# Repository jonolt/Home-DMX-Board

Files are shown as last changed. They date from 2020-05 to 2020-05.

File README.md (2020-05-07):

# Home DMX - Hardware

is a simple arduino based DMX controller to controll led lights installed in your home to be used with DMX controllers and relais.

**Please Contact me if you wonna use the board, there may be unducumented bugs.**

The Firmware can be found in a extra git repository: [Home-DMX-Firmaware](https://github.com/jonolt/Home-DMX-Firmaware).

This Project started with [Home-DMX-Control](https://github.com/jonolt/Home-DMX-Control). Firmware and hardware are now in two repositories.

## Idea

The selection for the lighting scene in daily use should be as simple as possible. Therefore exactly two push buttons are used to move up and down in a list of lighting scenes. Since I am not a fan of idle transformers, a conventional light switch is used in my application to switch the whole system on and off. In the same way a corresponding scene could be set.

The individual scenes should be adjustable directly on the controller without additional hardware. The input of the scenes works like on lighting control desks without motor faders via potentiometer and buttons. To make the firmware easy (without programmer and co) and maintainable by everyone, an Arduino was used, because it has a USB converter and the IDE is easy to use and install.

The board has a DMX output and 4 PWM/IO Outputs as well as 2 inputs for button.

## Structure

The MAX481 (U2) is a transceiver for RS-485 and RS-422 communication based on DMX. It uses the TX and RX pins of the arduino. For a visual control of the DMX communication Leds are connected via buffer (U61).

Digital inputs and outputs a isolated via optocouplers (additional circuits are required to switch larger loads).

The display is controlled serially (SPI) via the library provided by the manufacturer.

The switches can be hardware or software or both debaunced. Theres also the option to connect them via diodes (D1-D4) to a interupt pin.

The board does not has to be fully equipt with the componets.

**External Power must be disconnected when programming the Ardino, when a DC/DC converter is used!**

### Hardware Logic (Isolated)

#### Button Input

A total of 4 buttons can be placed on the pcb. While SW2 and SW3 are hard wired SW1 and SW4 can be set up in 4 different ways to safe pins to use the hardware interupt:

1. **1 buttons 0 extra IO**: SW1 or SW2 are connected only to the Interrupt pin via Diode D1/D4 or a bridge at D1/D4. If an innterupt is triggered, and neither SW2 or SW3 pin is pulled low, SW1 or SW4 must have been pressed.
2. **2 buttons 1 extra IO**: as in one but with JP1/JP2 bridged and SW1/SW4 fully equiped.
3. **2 buttons 2 extra IO**: equip all parts and bridge JP1 and JP2. Interrupt can still be used for other things.
4. **1 buttons 1 extra IO**: as in 3. but with either SW1 or SW4

Of course the swictehs can be used withiout the interrupt by ommiting the diodes. In fact even the low pass filete can be ommited with proper software debouncing.

All Switches and the interupt line are pulled up by R1 to R4 and R9. R4, C1 ect. build low pass filter for hardware debouncing and can be ommited (with the resistors bridged).

Swicth 2 and 3 have an additional Isolated input for external switches operating on another voltage level or with different ground.

#### LCD-Display

The LCD-Display is controlled by 3 Wire SPI connected to the Hardwre SPI of the microcontroller. The MISO master input is not required for the display and is kept free in case additional SPI devices are added (for example via a shield). The Backlight is PWM dimmed (D11) via the transisor Q1.

#### Expansion Connector J1 J2

The Connector(s) has the identical pinout as the Arduino Micro. Also you could use a stackable female connector strip directly with the Arduino.

#### LEDs

In addition to a power LED (D6), there are various Status LEDs on the front side (pcb-back) showing the correct function of the PWM Outputs (D20-23) and the DMX Interface (D60, D61). The LED of the Arduino can be used as a system LED if D13 is not used otherwise.

### Hardware Interfaces (Unisoltated)

All outputs and inputs (connectors) are isolated by default to each other. Resitor Bridges bridges can be apllied (1XX, 2XX) to break those isolations, see chapter Hardware Bridging.

#### X30 - Button Input

Simple current limiting Resistor R30 and R31 for diode of the photocoupler. Needs to be selected for each application by the input voltage V_IN with the formular:

R=(V_IN-V_F)/I_F, V_F=1.2V I_F=20mA

#### X40 - PWM/Output

These autputs can be used in 2 ways. As digital output with pullups and as Low Side switch (max 50mA, V_CE=0.1-0.2V).

The voltage for the pullups can cpme from the connector, directly bridged from the input power (R140) or via the linear voltage regulator U140, R142 and R143 (kater ones bridging isolation).

The emmiters of the photocouplers can be accessed directly via J41-J43 and J40-2. Conection between those can be broken at the Jumpers JP40-JP42. This way all four outputs can be used iolsated to each other.

#### X50 - Power In

Power input conssits of two parts revers voltage protection and DCDC-Converter. The reverse voltage protection is a siple p channel circuit. For the DCDC-Converter are two footprints obove each other. One for a SIL7 package (with pins 1,2,4,6 connected) and one for a SIL8 package (with pin (1, 2, (3), 6, 7 connected) to allow for different converters to be installed.

#### X60 - DMX

DMX uses the TX/RX pins of the arduino. The MAX481 (U60) is a common RS-485 tranciver. See [www.mathertel.de/Arduino/DMXShield.aspx](http://www.mathertel.de/Arduino/DMXShield.aspx) for a detailed description.

### Hardware Bridging

Danger Zone. Only assemble these components if you know what you are doing as this will bridge isolations.

#### 1XX

Bridges between unisolated interfaces:

- **R130, R131**: VIN/GND to PWM/Ouitput
- **R140, R141**: VIN/GND to Button Input

#### 2XX

Bridges between unisolated interfaces and isolated internal circuit:

- **J250, J251**: Connect these Pads with a wire to use the buildin voltage regulator of the arduino (VIN).
- **R260-R264**: Bypass isolation of DMX interface.

## License and Copyright

Copyright (C) 2019, 2020 Johannes Nolte
 
This program is free software: you can redistribute it and/or modify
it under the terms of the GNU General Public License as published by
the Free Software Foundation, version 2.1 only.

This program is distributed in the hope that it will be useful,
but WITHOUT ANY WARRANTY; without even the implied warranty of
MERCHANTABILITY or FITNESS FOR A PARTICULAR PURPOSE.  See the
GNU General Public License for more details.

You should have received a copy of the GNU General Public License
along with this program.  If not, see <https://www.gnu.org/licenses/>.

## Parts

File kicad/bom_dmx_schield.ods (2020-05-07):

 |  |  |  |  |  | Source: | /home/johannes/LRZPrivat/Sebastian/Home-DMX-Control/board/dmx_schield.sch
 |  |  |  |  |  | Date: | Sat 02 May 2020 13:36:19 CEST
 |  |  |  |  |  | Tool: | Eeschema 5.0.2+dfsg1-1
 |  |  |  |  |  | Generator: | /usr/share/kicad/plugins/bom_csv_grouped_by_value_with_fp.py
 |  |  |  |  |  | Component Count: | 102
 |  | All | Seb Qt | Sum All | Sum Seb | Ref | Qnty | Value | Cmp name | Footprint | Description | Vendor
KEM X5R0805 1,0U | 8 | 0.07 € | 4 | 0.28 € | 0.28 € | C3, C2, C1, C4, | 4 | 1u | C | Capacitor_SMD:C_0805_2012Metric | Unpolarized capacitor
KEM X7R0805 100N | 2 | 0.05 € | 0 | 0.10 € | 0.00 € | C6, C60, | 2 | 0,1uF | C | Capacitor_SMD:C_0805_2012Metric | Unpolarized capacitor
KEM X7R1206 4,7N | 2 | 0.02 € | 1 | 0.02 € | 0.02 € | C50, | 1 | 4,7uF/50V | C | Capacitor_SMD:C_1206_3216Metric | Unpolarized capacitor
KEM X7R1206 2,2N | 2 | 0.06 € | 1 | 0.06 € | 0.06 € | C51, | 1 | 2,2uF/50V | C | Capacitor_SMD:C_1206_3216Metric | Unpolarized capacitor
KEM X5R0805 10U | 1 | 0.15 € | 0 | 0.15 € | 0.00 € | C61, | 1 | 10uF | C | Capacitor_SMD:C_1206_3216Metric | Unpolarized capacitor
BAS 85 SMD | 6 | 0.05 € | 2 | 0.20 € | 0.10 € | D3, D2, D4, D1, | 4 | BAS85 | D_Schottky | Diode_SMD:D_MicroMELF | Schottky diode
OSO LHR974 | 2 | 0.05 € | 1 | 0.05 € | 0.05 € | D6, | 1 | LH R974 | LED | LED_SMD:LED_0805_2012Metric | Light emitting diode
TZMC15 | 2 | 0.30 € | 1 | 0.30 € | 0.30 € | D50, | 1 | TZM15 | D_Zener | Diode_SMD:D_SC-80 | Zener diode
OSO LGR971 | 10 | 0.05 € | 4 | 0.30 € | 0.20 € | D61, D60, D23, D22, D21, D20, | 6 | LG R971 | LED | LED_SMD:LED_0805_2012Metric | Light emitting diode
- | 8 | 0.00 € | 4 | 0.00 € | 0.00 € | H1, H2, H3, H4, | 4 | MountingHole | MountingHole | MountingHole:MountingHole_3.2mm_M3_DIN965 | Mounting Hole without connection
MPE 094-1-007 + MPE 094-1-010 | 2 | 0.49 € | 0 | 0.98 € | 0.00 € | J1, J2, | 2 | Conn_01x17 | Conn_01x17 | Connector_PinSocket_2.54mm:PinSocket_1x17_P2.54mm_Vertical | Generic connector, single row, 01x17, script generated (kicad-library-utils/schlib/autogen/connector/)
AKL 382-04 + AKL 369-04 | 2 | 1.52 € | 1 | 1.52 € | 1.52 € | J30, | 1 | Conn_01x04 | Conn_01x04 | Connector_Phoenix_MC:PhoenixContact_MC_1,5_4-G-3.81_1x04_P3.81mm_Horizontal | Generic connector, single row, 01x04, script generated (kicad-library-utils/schlib/autogen/connector/)
AKL 382-06 + AKL 369-06 | 2 | 2.00 € | 1 | 2.00 € | 2.00 € | J40, | 1 | Conn_01x06 | Conn_01x06 | Connector_Phoenix_MC:PhoenixContact_MC_1,5_6-G-3.81_1x06_P3.81mm_Horizontal | Generic connector, single row, 01x06, script generated (kicad-library-utils/schlib/autogen/connector/)
AKL 382-02 + AKL 369-02 | 2 | 0.75 € | 1 | 0.75 € | 0.75 € | J50, | 1 | Conn_01x02 | Conn_01x02 | Connector_Phoenix_MC:PhoenixContact_MC_1,5_2-G-3.81_1x02_P3.81mm_Horizontal | Generic connector, single row, 01x02, script generated (kicad-library-utils/schlib/autogen/connector/)
AKL 382-03 + AKL 369-03 | 1 | 1.14 € | 0 | 1.14 € | 0.00 € | J60, | 1 | Conn_01x03 | Conn_01x03 | Connector_Phoenix_MC:PhoenixContact_MC_1,5_3-G-3.81_1x03_P3.81mm_Horizontal | Generic connector, single row, 01x03, script generated (kicad-library-utils/schlib/autogen/connector/)
- | 5 |  |  | 0.00 € | 0.00 € | J251, J250, J42, J41, J43, | 5 | Conn_01x01 | Conn_01x01 | Connector_Wire:SolderWirePad_1x01_Drill0.8mm | Generic connector, single row, 01x01, script generated (kicad-library-utils/schlib/autogen/connector/)
- | 2 |  |  | 0.00 € | 0.00 € | JP1, JP2, | 2 | SolderJumper_2_Open | SolderJumper_2_Open | Jumper:SolderJumper-2_P1.3mm_Open_Pad1.0x1.5mm | Solder Jumper, 2-pole, open
- | 3 |  |  | 0.00 € | 0.00 € | JP40, JP41, JP42, | 3 | SolderJumper_2_Bridged | SolderJumper_2_Bridged | Jumper:SolderJumper-2_P1.3mm_Bridged_Pad1.0x1.5mm | Solder Jumper, 2-pole, closed/bridged
BOU SRN4018-4R7M | 2 | 0.25 € | 1 | 0.25 € | 0.25 € | L50, | 1 | 4,7uH/1.15A | L | Inductor_SMD:L_Bourns-SRN4018 | Inductor
EA DOGM162E-A (evtl L/S) + EA LED55X31-A (W) | 2 | 11.95 € | 1 | 11.95 € | 11.95 € | LCD1, | 1 | EADOGM162 | EADOGM162 | my_LCD:EA DOGM 162
BSR 14 SMD | 2 | 0.07 € | 1 | 0.07 € | 0.07 € | Q1, | 1 | BSR14 | Q_NPN_BEC | Package_TO_SOT_SMD:SOT-23 | NPN transistor, base/emitter/collector
IRLML 5203 | 2 | 0.25 € | 1 | 0.25 € | 0.25 € | Q50, | 1 | IRLML5203 | Q_PMOS_GSD | Package_TO_SOT_SMD:SOT-23 | P-MOSFET transistor, gate/source/drain
RND 0805 1 10K | 9 | 0.00 € |  | 0.00 € | 0.00 € | R1, R3, R2, R40, R41, R42, R43, R4, R9, | 9 | 10k | R | Resistor_SMD:R_0805_2012Metric | Resistor
optional | 2 | 0.00 € | 0 | 0.00 € | 0.00 € | R10, R11, | 2 | 5-10k | R | Resistor_SMD:R_0805_2012Metric | Resistor
RND 0805 1 10 | 1 |  |  | 0.00 € | 0.00 € | R12, | 1 | 10 | R | Resistor_SMD:R_0805_2012Metric | Resistor
RND 0805 1 1K | 5 | 0.00 € |  | 0.00 € | 0.00 € | R13, R7, R6, R5, R8, | 5 | 1,0k | R | Resistor_SMD:R_0805_2012Metric | Resistor
RND 0805 1 330 | 1 | 0.00 € |  | 0.00 € | 0.00 € | R14, | 1 | 330 | R | Resistor_SMD:R_0805_2012Metric | Resistor
RND 0805 1 560 | 2 |  |  | 0.00 € | 0.00 € | R31, R30, | 2 | 540@12V | R | Resistor_SMD:R_0805_2012Metric | Resistor
RND 0805 1 100K | 1 | 0.00 € |  | 0.00 € | 0.00 € | R50, | 1 | 100k | R | Resistor_SMD:R_0805_2012Metric | Resistor
RND 0805 1 120 | 1 | 0.00 € |  | 0.00 € | 0.00 € | R60, | 1 | 120 | R | Resistor_SMD:R_0805_2012Metric | Resistor
RND 0805 1 560 | 2 |  |  | 0.00 € | 0.00 € | R62, R61, | 2 | 562 | R | Resistor_SMD:R_0805_2012Metric | Resistor
RND 0805 1 300 | 6 |  |  | 0.00 € | 0.00 € | R64, R20, R21, R22, R23, R63, | 6 | 300 | R | Resistor_SMD:R_0805_2012Metric | Resistor
RND 0805 1 0 | 9 |  |  | 0.00 € | 0.00 € | R130, R261, R260, R262, R263, R264, R131, R140, R141, | 9 | 0 | R | Resistor_SMD:R_0805_2012Metric | Resistor
RND 0805 1 240 | 1 |  |  | 0.00 € | 0.00 € | R142, | 1 | 240 | R | Resistor_SMD:R_0805_2012Metric | Resistor
find si sho was | 1 | 0.00 € | 0 | 0.00 € | 0.00 € | R143, | 1 | e.g. 2k | R | Resistor_SMD:R_0805_2012Metric | Resistor
ACP 9-LRS 10K + ACHSE ACP 9 G | 4 | 0.32 € | 2 | 0.64 € | 0.64 € | RV1, RV2, | 2 | 10k | R_POT | Potentiometer_THT:Potentiometer_ACP_CA9-V10_Vertical | Potentiometer
OMR B3FS-1012P | 7 | 0.32 € | 3 | 1.28 € | 0.96 € | SW1, SW3, SW2, SW4, | 4 | SW_Push | SW_Push | Button_Switch_SMD:SW_SPST_PTS645 | Push button switch, generic, two pins
1S7E_1205S1.5UP | 2 | 3.10 € | 1 | 3.10 € | 3.10 € | U1, | 1 | TEC 2-2411WI | DCDC-SIP8-1-2-(3)-6-7 | my_lib:SIP8-1-2-3-5-6-7-8 | DCDC Converter Single SIL Package
LTV 847S | 2 | 0.65 € | 1 | 0.65 € | 0.65 € | U3, | 1 | LTV-847S | LTV-847S | Package_DIP:SMDIP-16_W7.62mm | DC Optocoupler, Vce 35V, CTR 50%, SMDIP-16
LTV 827S | 1 | 0.25 € | 0 | 0.25 € | 0.00 € | U5, | 1 | LTV-827S | LTV-827S | Package_DIP:SMDIP-8_W7.62mm | DC Optocoupler, Vce 35V, CTR 50%, SMDIP-8
ADUM 1301 ARW | 1 | 2.30 € | 0 | 2.30 € | 0.00 € | U6, | 1 | ADUM1301 | ADUM1301 | Package_SO:SOIC-16W_7.5x10.3mm_P1.27mm | Triple-Channel Digital Isolators
REE-0505S | 1 | 2.90 € | 0 | 2.90 € | 0.00 € | U7, | 1 | REE-0505S/1S7E_0505S1.5UP | DCDC-SIP7-1-2-4-6 | my_lib:SIP7-1-2-4-6 | DCDC Converter Single SIL Package
2S7WA_0505S3RP | 1 | 8.25 € | 0 | 8.25 € | 0.00 € | U11, | 1 | DCDC-SIP7-1-2-4-6 | DCDC-SIP7-1-2-4-6 | my_lib:SIP7-1-2-4-6 | DCDC Converter Single SIL Package
MAX 481 CSA | 1 | 3.10 € | 0 | 3.10 € | 0.00 € | U60, | 1 | MAX481E | MAX481E | Package_SO:PowerIntegrations_SO-8 | Half duplex RS-485/RS-422, 2.5 Mbps, Â±15kV electro-static discharge (ESD) protection, no slew-rate, with low-power shutdown, with receiver/driver enable, 32 receiver drive kapacitity, DIP-8 and SOIC-8
74LVC2G34 | 1 | 0.00 € |  | 0.00 € | 0.00 € | U61, | 1 | 74LVC2G34 | 74LVC2G34 | Package_TO_SOT_SMD:SOT-23-6 | Dual Buffer, Low-Voltage CMOS, power-pins
LM 317 MDCYR | 1 | 0.78 € |  | 0.78 € | 0.00 € | U140, | 1 | LM317_3PinPackage | LM317_3PinPackage | Package_TO_SOT_SMD:SOT-223-3_TabPin2 | 1A 35V Adjustable Linear Regulator, SOT-89/SOT-223/TO-220/TO-252/TO-263
ARDUINO MICRO WOH | 2 | 17.30 € | 1 | 17.30 € | 17.30 € | XA1, | 1 | Arduino_Micro_Socket | Arduino_Micro_Socket | Arduino:Arduino_Micro_Socket | Socket for Arduino Micro
Board | 1 | 10.30 € | 1 | 10.30 € | 10.30 €
 |  |  |  | 71.22 € | 50.75 €
 |  |  |  |  |  | U1x1, U11x1
3S7A_0505S1.5UP |  | 6.40 €
TMH 0505S |  | 6.65

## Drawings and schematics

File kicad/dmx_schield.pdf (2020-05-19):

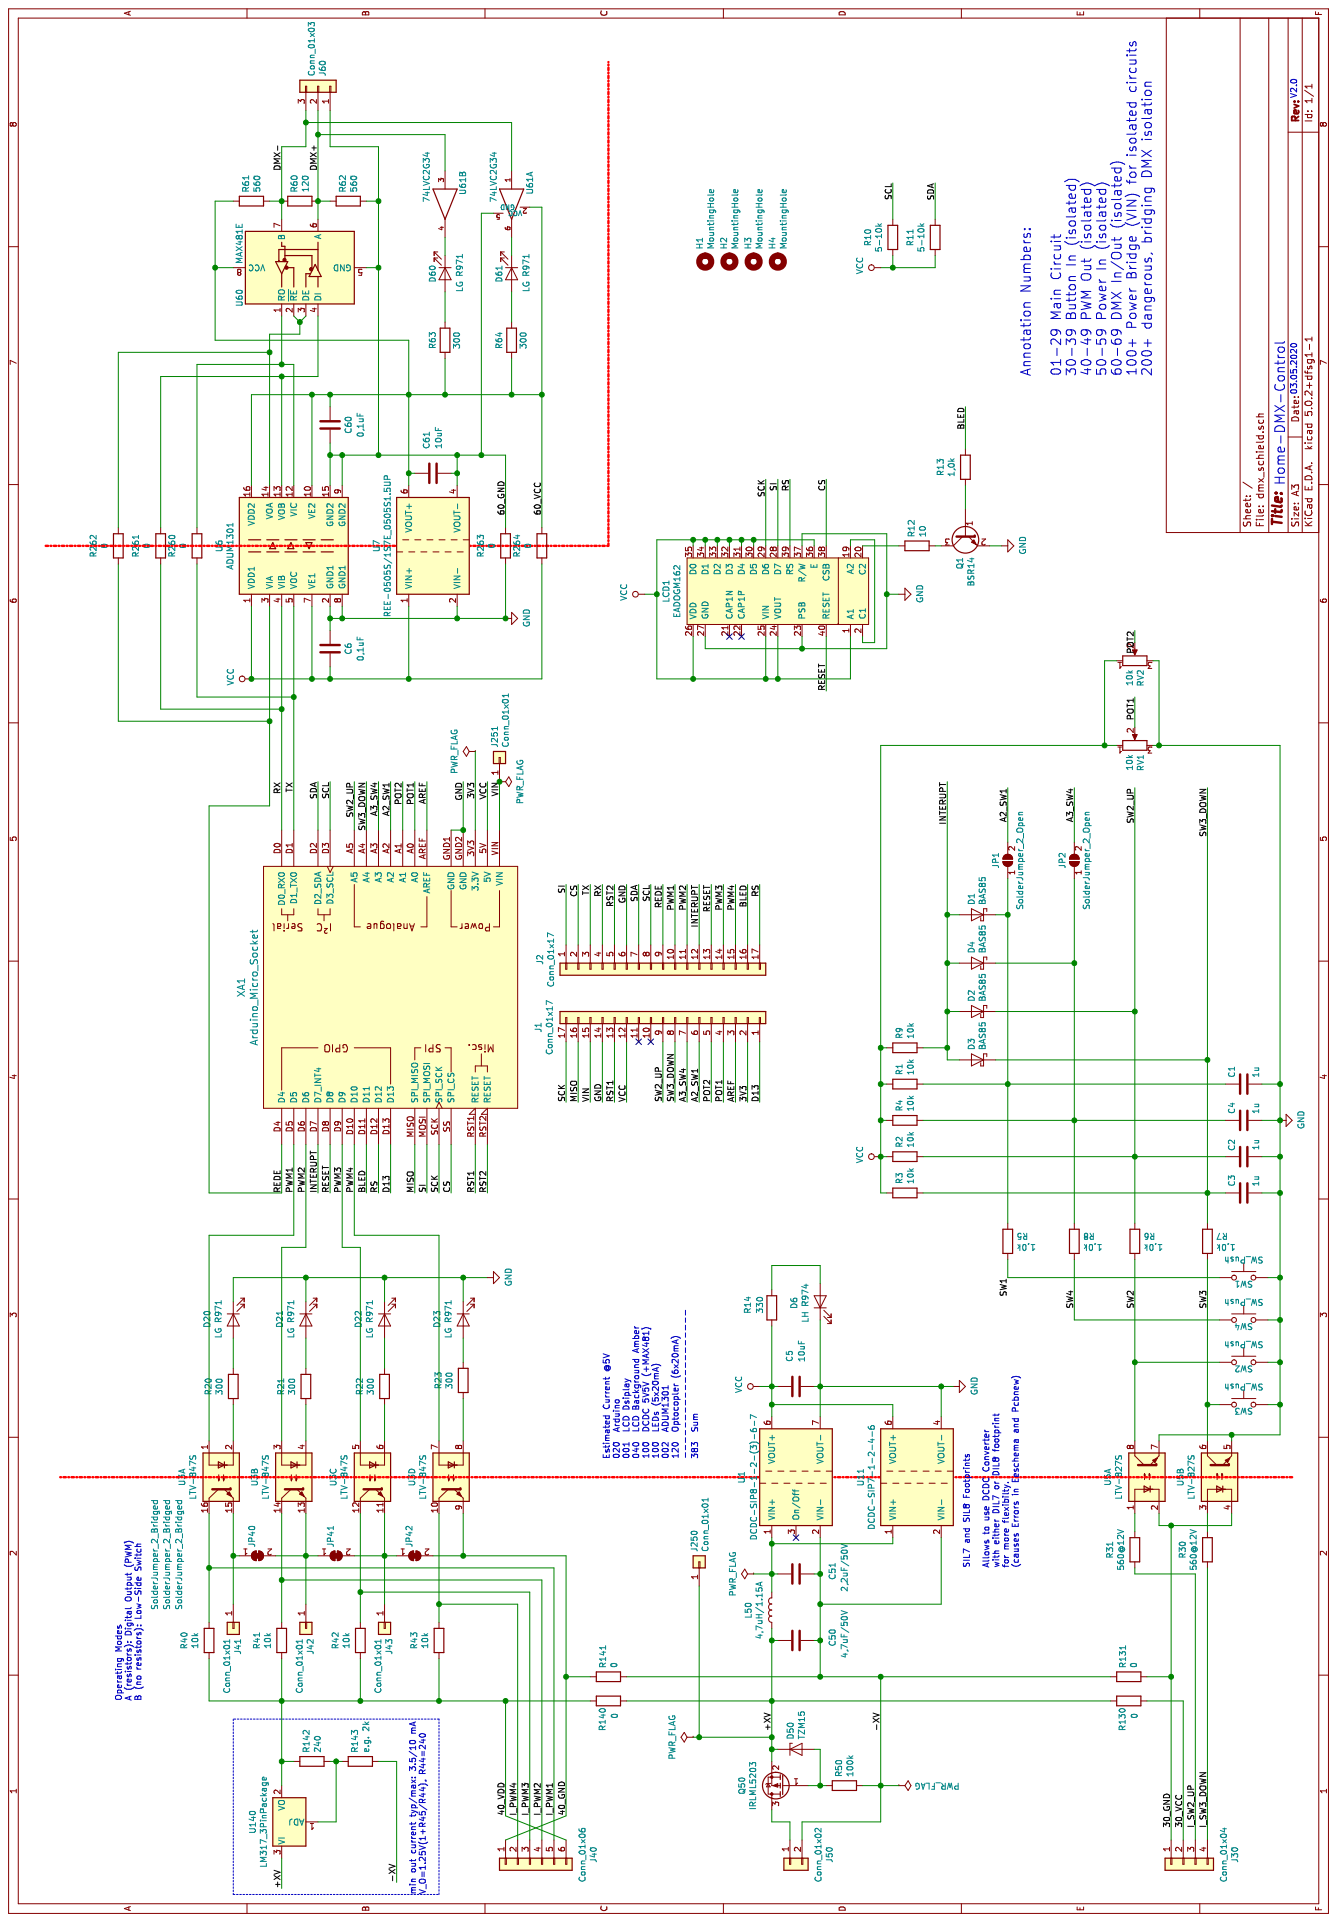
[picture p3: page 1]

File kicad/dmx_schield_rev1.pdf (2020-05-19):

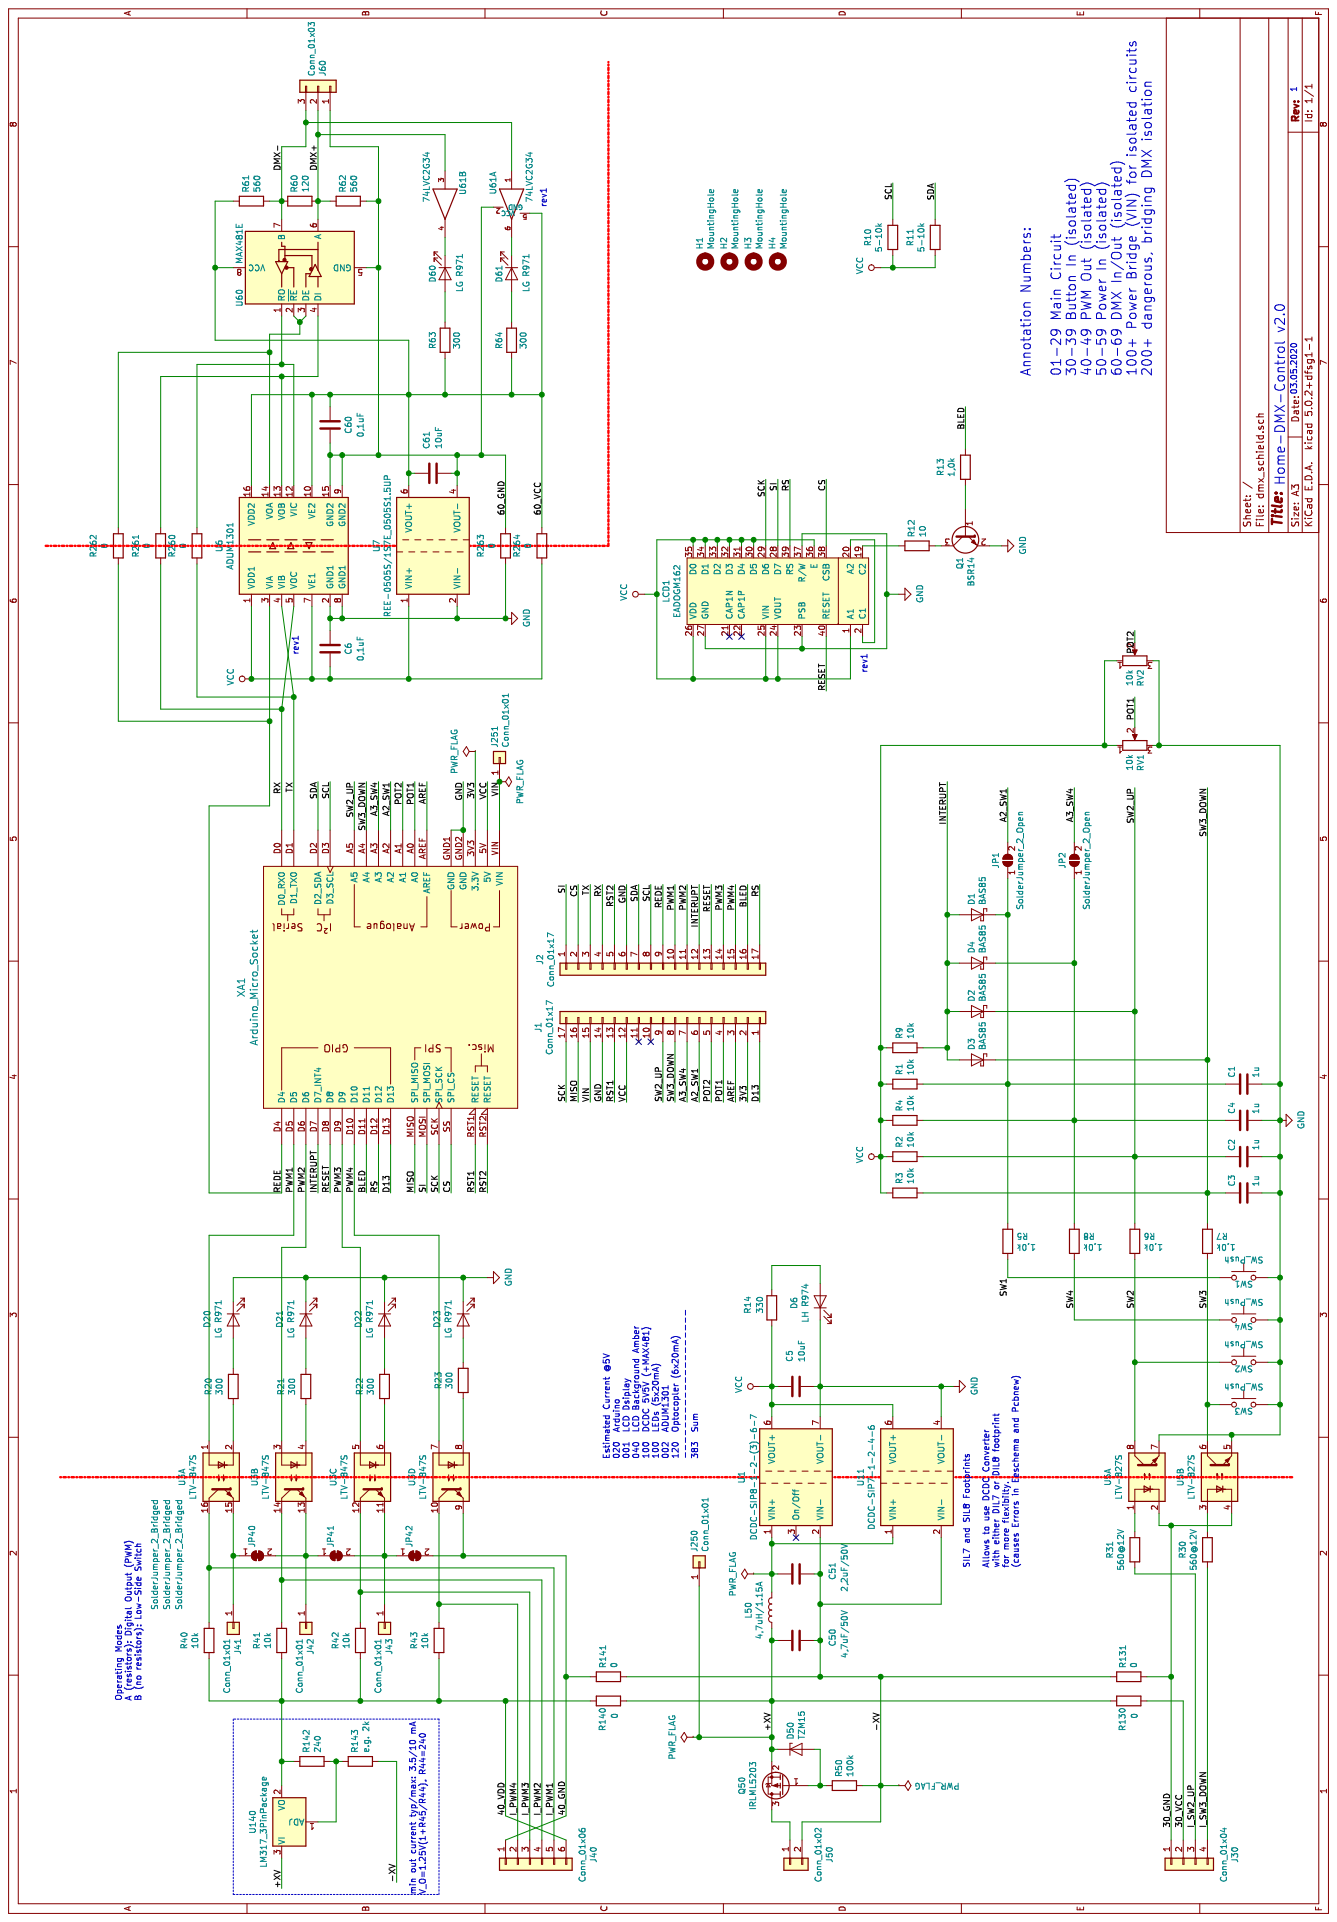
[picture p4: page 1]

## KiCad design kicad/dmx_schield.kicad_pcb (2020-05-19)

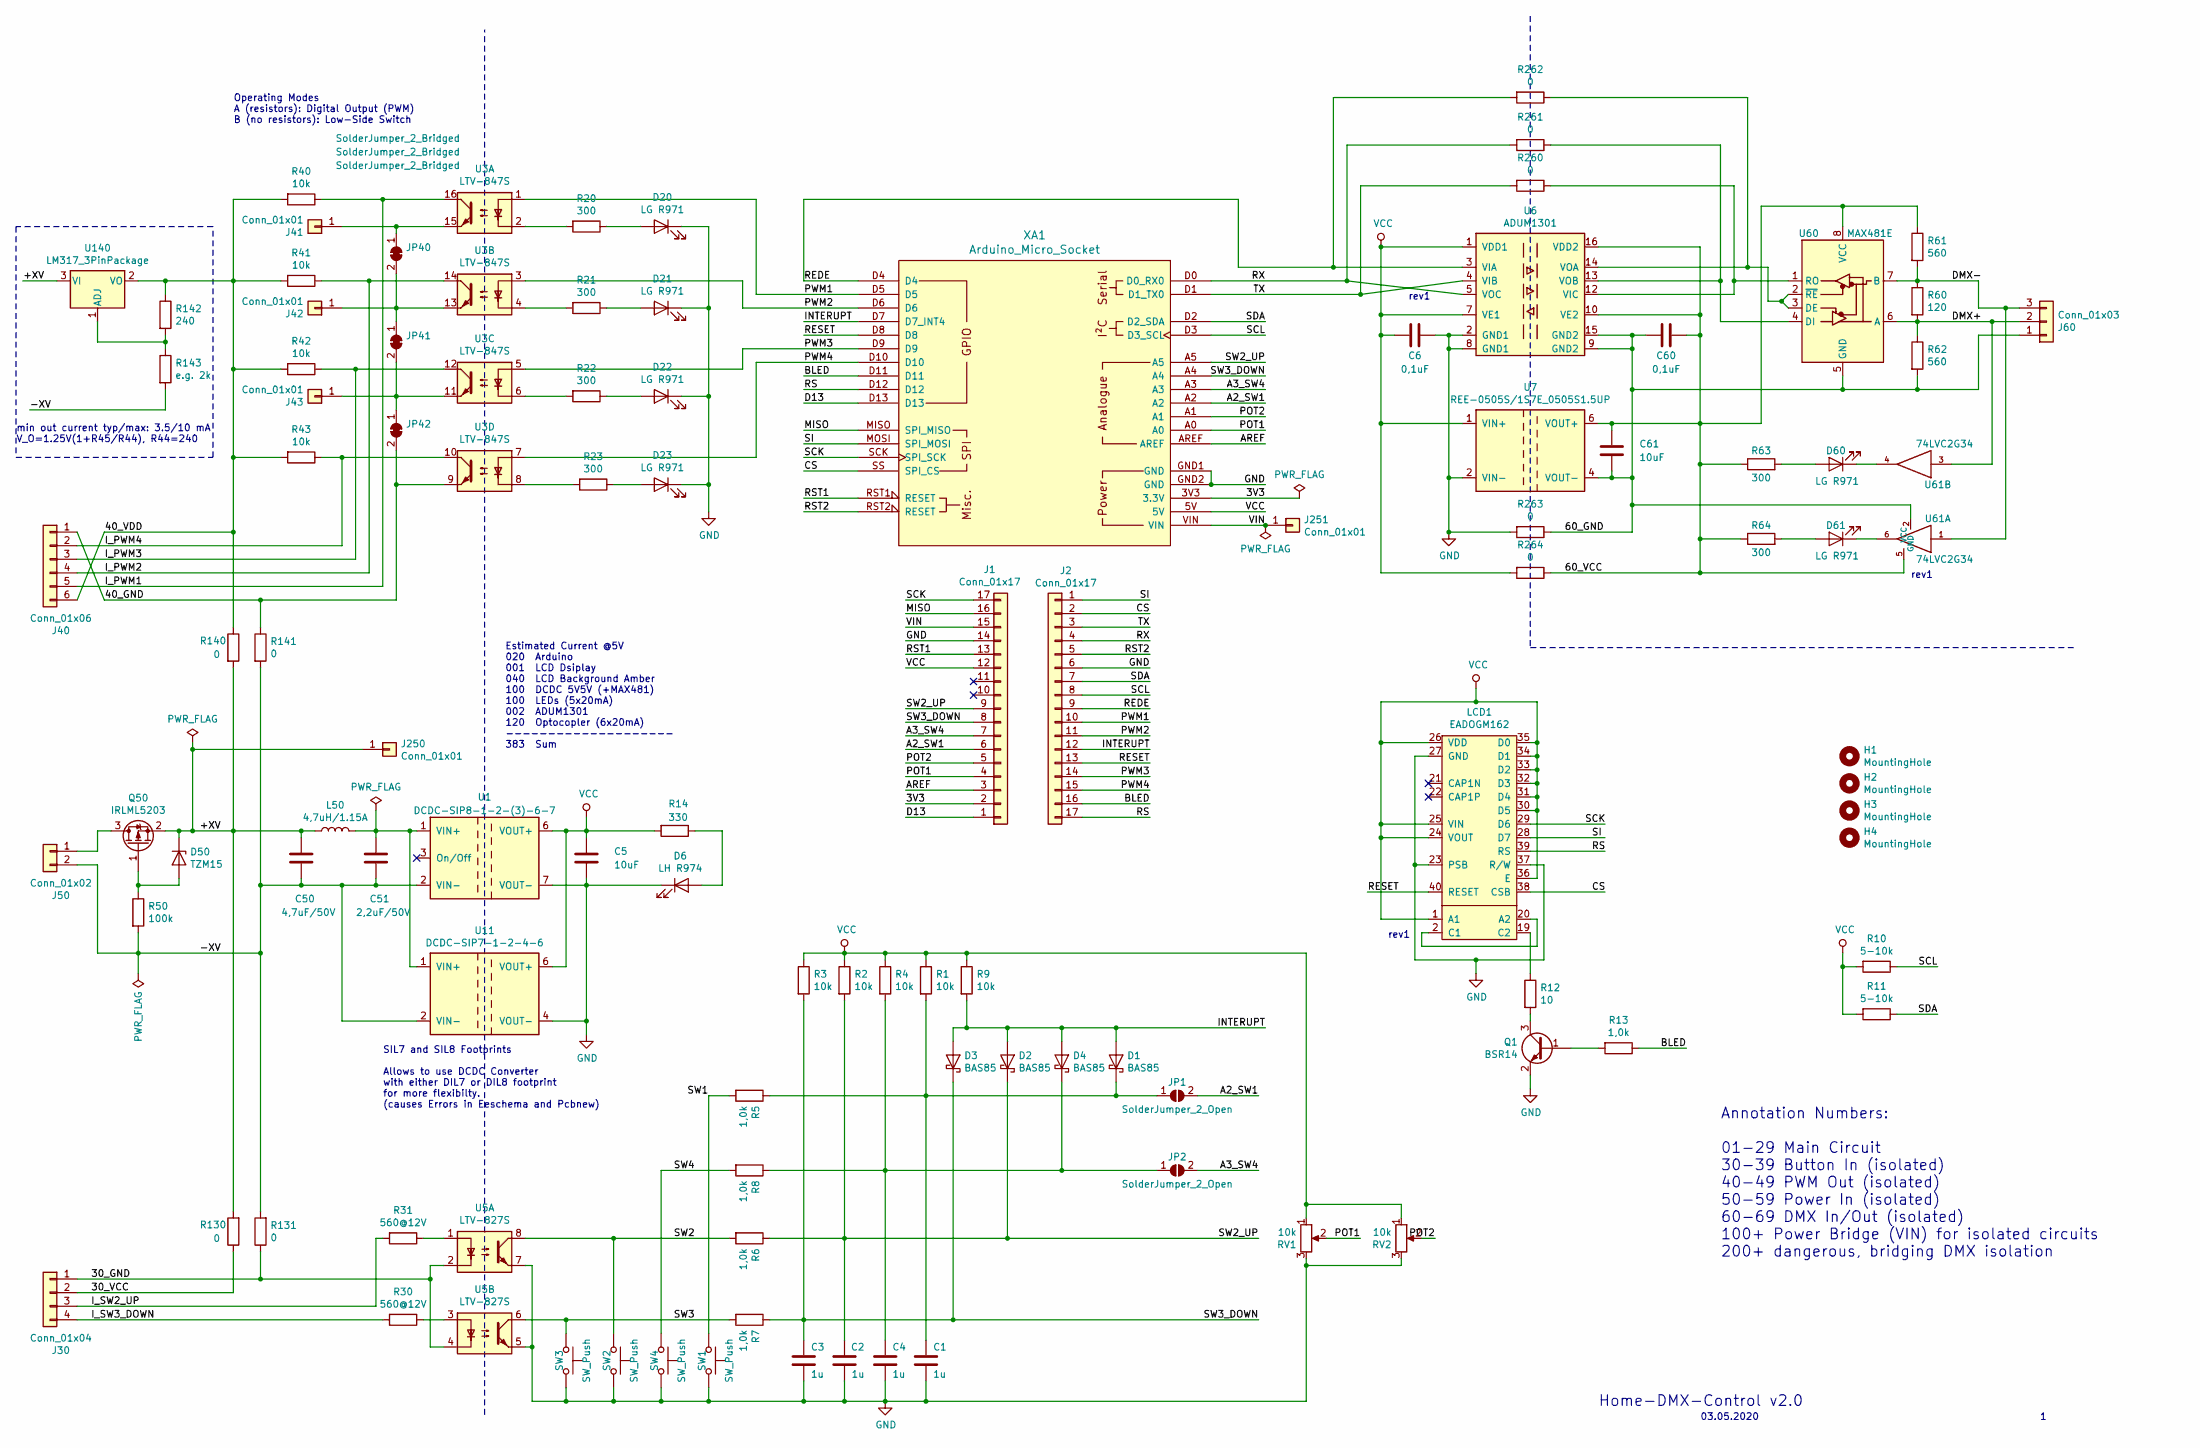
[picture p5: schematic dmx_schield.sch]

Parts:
C1, C2, C3, C4: 1u; C_0805_2012Metric
C5, C61: 10uF; C_1206_3216Metric
C6, C60: 0,1uF; C_0805_2012Metric
C50: 4,7uF/50V; C_1206_3216Metric
C51: 2,2uF/50V; C_1206_3216Metric
D1, D2, D3, D4: BAS85; D_MicroMELF
D6: LH R974; LED_0805_2012Metric
D20, D21, D22, D23, D60, D61: LG R971; LED_0805_2012Metric
D50: TZM15; D_SC-80
H1, H2, H3, H4: MountingHole; MountingHole_3.2mm_M3_DIN965
J1, J2: Conn_01x17; PinSocket_1x17_P2.54mm_Vertical
J30: Conn_01x04; PhoenixContact_MC_1,5_4-G-3.81_1x04_P3.81mm_Horizontal
J40: Conn_01x06; PhoenixContact_MC_1,5_6-G-3.81_1x06_P3.81mm_Horizontal
J41, J42, J43, J250, J251: Conn_01x01; SolderWirePad_1x01_Drill0.8mm
J50: Conn_01x02; PhoenixContact_MC_1,5_2-G-3.81_1x02_P3.81mm_Horizontal
J60: Conn_01x03; PhoenixContact_MC_1,5_3-G-3.81_1x03_P3.81mm_Horizontal
JP1, JP2: SolderJumper_2_Open; SolderJumper-2_P1.3mm_Open_Pad1.0x1.5mm
JP40, JP41, JP42: SolderJumper_2_Bridged; SolderJumper-2_P1.3mm_Bridged_Pad1.0x1.5mm
L50: 4,7uH/1.15A; L_Bourns-SRN4018
LCD1: EADOGM162; EA_DOGM_162
Q1: BSR14; SOT-23
Q50: IRLML5203; SOT-23
R1, R2, R3, R4, R9, R40, R41, R42, R43: 10k; R_0805_2012Metric
R5, R6, R7, R8, R13: 1,0k; R_0805_2012Metric
R10, R11: 5-10k; R_0805_2012Metric
R12: 10; R_0805_2012Metric
R14: 330; R_0805_2012Metric
R20, R21, R22, R23, R63, R64: 300; R_0805_2012Metric
R30, R31: 560@12V; R_0805_2012Metric
R50: 100k; R_0805_2012Metric
R60: 120; R_0805_2012Metric
R61, R62: 560; R_0805_2012Metric
R130, R131, R140, R141, R260, R261, R262, R263, R264: 0; R_0805_2012Metric
R142: 240; R_0805_2012Metric
R143: e.g. 2k; R_0805_2012Metric
RV1, RV2: 10k; Potentiometer_ACP_CA9-V10_Vertical
SW1, SW2, SW3, SW4: SW_Push; SW_SPST_PTS645
U1: DCDC-SIP8-1-2-(3)-6-7; SIP8-1-2-3-5-6-7-8
U3: LTV-847S; SMDIP-16_W7.62mm
U5: LTV-827S; SMDIP-8_W7.62mm
U6: ADUM1301; SOIC-16W_7.5x10.3mm_P1.27mm
U7: REE-0505S/1S7E_0505S1.5UP; SIP7-1-2-4-6
U11: DCDC-SIP7-1-2-4-6; SIP7-1-2-4-6
U60: MAX481E; PowerIntegrations_SO-8
U61: 74LVC2G34; SOT-23-6
U140: LM317_3PinPackage; SOT-223-3_TabPin2
XA1: Arduino_Micro_Socket

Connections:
/3V3: J1.2, XA1.3V3 (3.3V)
/30_GND: J30.1, R131.1, U5.2, U5.4
/30_VCC: J30.2, R130.1
/40_GND: J40.1, JP42.2 (B), R141.1, U3.9
/40_VDD: J40.6, R40.2, R41.2, R42.2, R43.2, R140.1, R142.1, U140.2 (VO)
/60_GND: C60.2, C61.1, J60.1, R62.2, R263.1, U6.9 (GND2), U6.15 (GND2), U7.4 (VOUT-), U60.5 (GND), U61.2 (GND)
/60_VCC: C60.1, C61.2, R61.1, R63.1, R64.1, R264.1, U6.10 (VE2), U6.16 (VDD2), U7.6 (VOUT+), U60.8 (VCC), U61.5 (VCC)
/+XV: C50.1, D50.1 (K), J250.1, L50.1, Q50.2 (S), R130.2, R140.2, U140.3 (VI)
/-XV: C50.2, C51.2, J50.2, R50.2, R131.2, R141.2, R143.2, U1.2 (VIN-), U11.2 (VIN-)
/A2_SW1: J1.6, JP1.2 (B), XA1.A2
/A3_SW4: J1.7, JP2.2 (B), XA1.A3
/AREF: J1.3, XA1.AREF
/BLED: J2.16, R13.1, XA1.D11
/CS: J2.2, LCD1.38 (CSB), XA1.SS (SPI_CS)
/D13: J1.1, XA1.D13
/DMX+: J60.2, R60.2, R62.1, U60.6 (A), U61.3
/DMX-: J60.3, R60.1, R61.2, U60.7 (B), U61.1
/INTERUPT: D1.2 (A), D2.2 (A), D3.2 (A), D4.2 (A), J2.12, R9.2, XA1.D7 (D7_INT4)
/I_PWM1: J40.5, R40.1, U3.16
/I_PWM2: J40.4, R41.1, U3.14
/I_PWM3: J40.3, R42.1, U3.12
/I_PWM4: J40.2, R43.1, U3.10
/I_SW2_UP: J30.3, R31.2
/I_SW3_DOWN: J30.4, R30.2
/MISO: J1.16, XA1.MISO (SPI_MISO)
/POT1: J1.4, RV1.2, XA1.A0
/POT2: J1.5, RV2.2, XA1.A1
/PWM1: J2.10, U3.1, XA1.D5
/PWM2: J2.11, U3.3, XA1.D6
/PWM3: J2.14, U3.5, XA1.D9
/PWM4: J2.15, U3.7, XA1.D10
/REDE: J2.9, R262.2, U6.3 (VIA), XA1.D4
/RESET: J2.13, LCD1.40 (RESET), XA1.D8
/RS: J2.17, LCD1.39 (RS), XA1.D12
/RST1: J1.13, XA1.RST1 (RESET)
/RST2: J2.5, XA1.RST2 (RESET)
/RX: J2.4, R261.2, U6.5 (VOC), XA1.D0 (D0_RX0)
/SCK: J1.17, LCD1.29 (D6), XA1.SCK (SPI_SCK)
/SCL: J2.8, R10.1, XA1.D3 (D3_SCL)
/SDA: J2.7, R11.1, XA1.D2 (D2_SDA)
/SI: J2.1, LCD1.28 (D7), XA1.MOSI (SPI_MOSI)
/SW1: R5.2, SW1.1
/SW2: R6.2, SW2.1, U5.8
/SW2_UP: C2.1, D2.1 (K), J1.9, R2.2, R6.1, XA1.A5
/SW3: R7.2, SW3.1, U5.6
/SW3_DOWN: C3.1, D3.1 (K), J1.8, R3.2, R7.1, XA1.A4
/SW4: R8.2, SW4.1
/TX: J2.3, R260.2, U6.4 (VIB), XA1.D1 (D1_TX0)
/VIN: J1.15, J251.1, XA1.VIN
GND: C1.2, C2.2, C3.2, C4.2, C5.1, C6.1, D6.1 (K), D20.1 (K), D21.1 (K), D22.1 (K), D23.1 (K), J1.14, J2.6, LCD1.23 (PSB), LCD1.27 (GND), LCD1.37 (R/W), Q1.2 (E), R263.2, RV1.3, RV2.3, SW1.2, SW2.2, SW3.2, SW4.2, U1.7 (VOUT-), U5.5, U5.7, U6.2 (GND1), U6.8 (GND1), U7.2 (VIN-), U11.4 (VOUT-), XA1.GND1 (GND), XA1.GND2 (GND)
unnamed: C1.1, D1.1 (K), JP1.1 (A), R1.2, R5.1
unnamed: C4.1, D4.1 (K), JP2.1 (A), R4.2, R8.1
unnamed: C51.1, L50.2, U1.1 (VIN+), U11.1 (VIN+)
unnamed: D6.2 (A), R14.1
unnamed: D20.2 (A), R20.1
unnamed: D21.2 (A), R21.1
unnamed: D22.2 (A), R22.1
unnamed: D23.2 (A), R23.1
unnamed: D50.2 (A), Q50.1 (G), R50.1
unnamed: D60.1 (K), U61.4
unnamed: D60.2 (A), R63.2
unnamed: D61.1 (K), U61.6
unnamed: D61.2 (A), R64.2
unnamed: J41.1, JP40.1 (A), U3.15
unnamed: J42.1, JP40.2 (B), JP41.1 (A), U3.13
unnamed: J43.1, JP41.2 (B), JP42.1 (A), U3.11
unnamed: J50.1, Q50.3 (D)
unnamed: LCD1.2 (C1), LCD1.20 (A2)
unnamed: LCD1.19 (C2), R12.1
unnamed: Q1.1 (B), R13.2
unnamed: Q1.3 (C), R12.2
unnamed: R20.2, U3.2
unnamed: R21.2, U3.4
unnamed: R22.2, U3.6
unnamed: R23.2, U3.8
unnamed: R30.1, U5.3
unnamed: R31.1, U5.1
unnamed: R142.2, R143.1, U140.1 (ADJ)
unnamed: R260.1, U6.12 (VIC), U60.1 (RO)
unnamed: R261.1, U6.13 (VOB), U60.4 (DI)
unnamed: R262.1, U6.14 (VOA), U60.2 (~RE), U60.3 (DE)
VCC: C5.2, C6.2, J1.12, LCD1.1 (A1), LCD1.24 (VOUT), LCD1.25 (VIN), LCD1.26 (VDD), LCD1.30 (D5), LCD1.31 (D4), LCD1.32 (D3), LCD1.33 (D2), LCD1.34 (D1), LCD1.35 (D0), LCD1.36 (E), R1.1, R2.1, R3.1, R4.1, R9.1, R10.2, R11.2, R14.2, R264.2, RV1.1, RV2.1, U1.6 (VOUT+), U6.1 (VDD1), U6.7 (VE1), U7.1 (VIN+), U11.6 (VOUT+), XA1.5V

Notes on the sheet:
03.05.2020
Operating Modes A (resistors): Digital Output (PWM) B (no resistors): Low-Side Switch
Estimated Current @5V 020 Arduino 001 LCD Dsiplay 040 LCD Background Amber 100 DCDC 5V5V (+MAX481) 100 LEDs (5x20mA) 002 ADUM1301 120 Optocopler (6x20mA) -------------------- 383 Sum
Annotation Numbers: 01-29 Main Circuit 30-39 Button In (isolated) 40-49 PWM Out (isolated) 50-59 Power In (isolated) 60-69 DMX In/Out (isolated) 100+ Power Bridge (VIN) for isolated circuits 200+ dangerous, bridging DMX isolation
SIL7 and SIL8 Footprints Allows to use DCDC Converter with either DIL7 or DIL8 footprint for more flexibilty. (causes Errors in Eeschema and Pcbnew)
min out current typ/max: 3.5/10 mA V_O=1.25V(1+R45/R44), R44=240
Home-DMX-Control v2.0
rev1

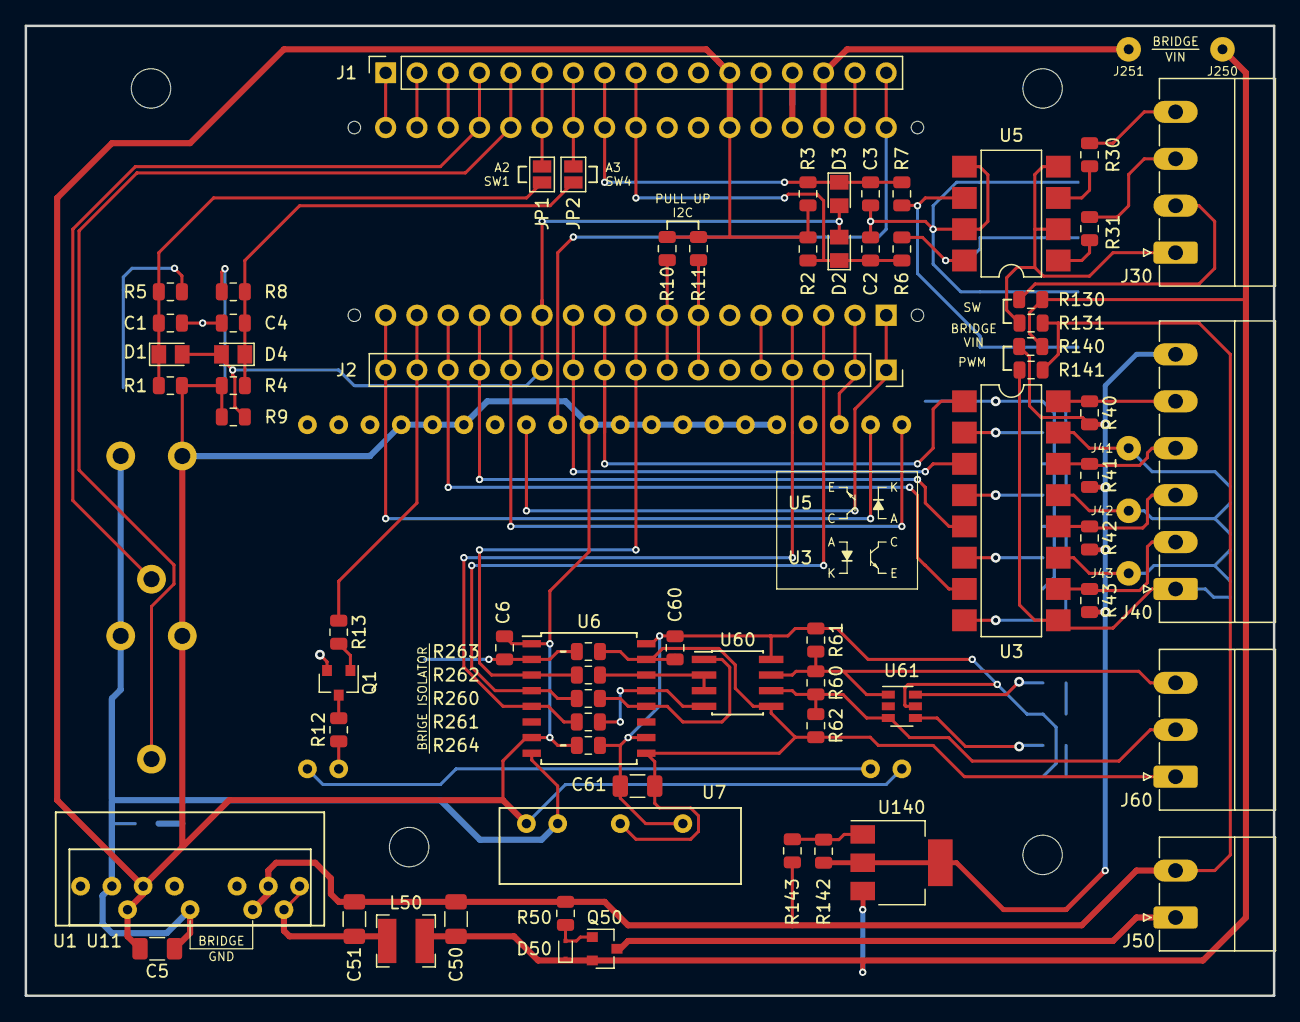
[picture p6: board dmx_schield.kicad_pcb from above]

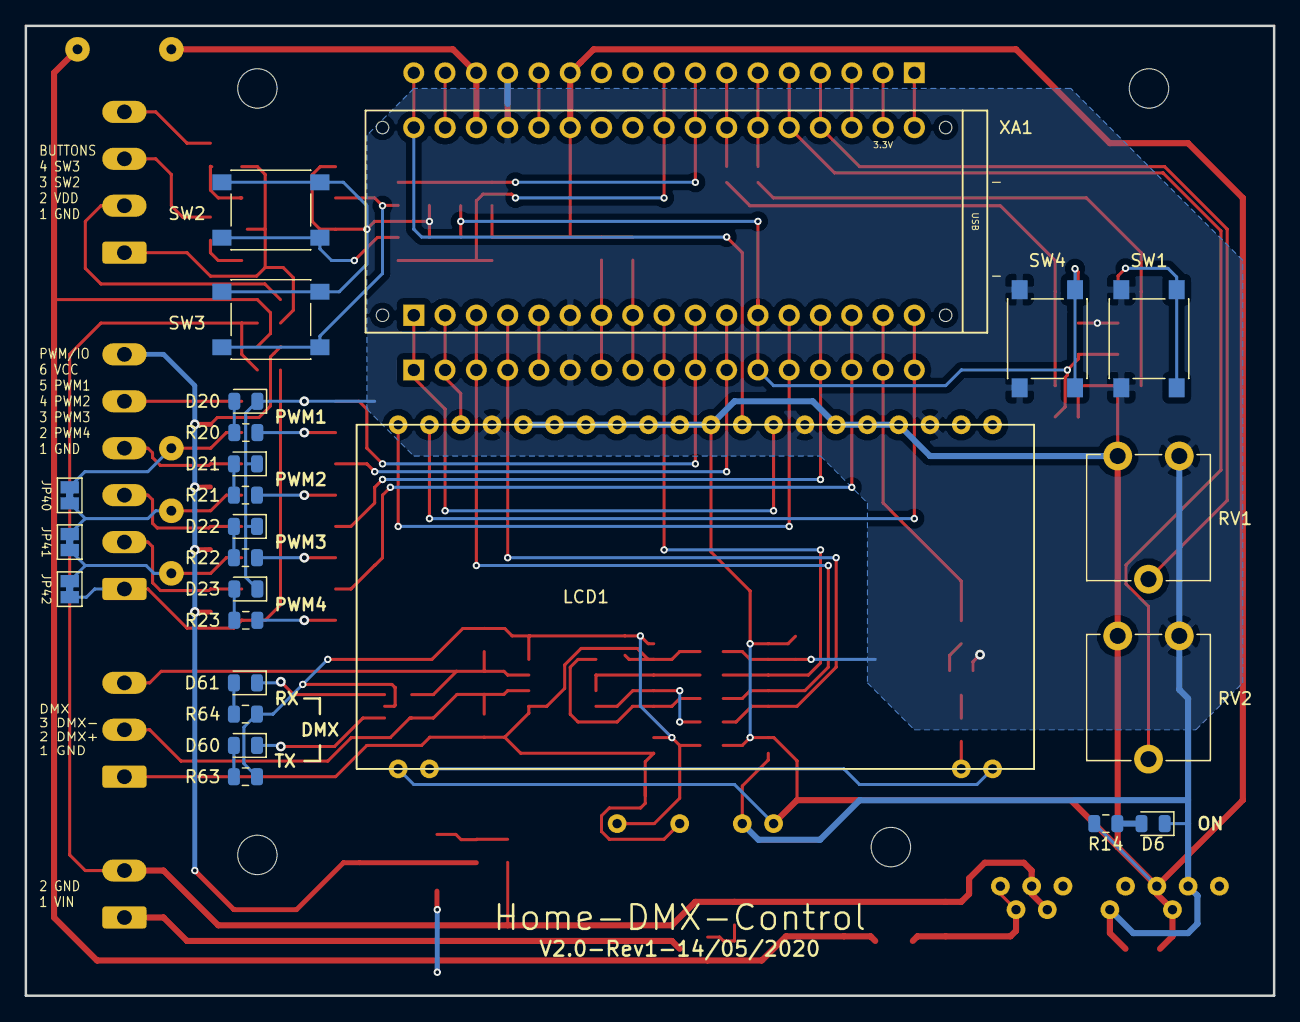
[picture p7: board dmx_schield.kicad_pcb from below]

Board: 2 copper layers, 101.3 x 78.7 mm, 103 parts (25 on the bottom side), 82 nets.
